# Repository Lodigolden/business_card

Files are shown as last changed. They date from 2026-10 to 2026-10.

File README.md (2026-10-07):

# Business Card

## Overview
I saw the idea for a PCB business card online, but for the most part the PCBs didn't actually do anything. I saw a fun opportunity to give anyone who's got the card a clock/thermometer that they might get some use out of.

## Use

## Build Your Own!
See the Bill of Materials (BoM) in the docs/ folder.

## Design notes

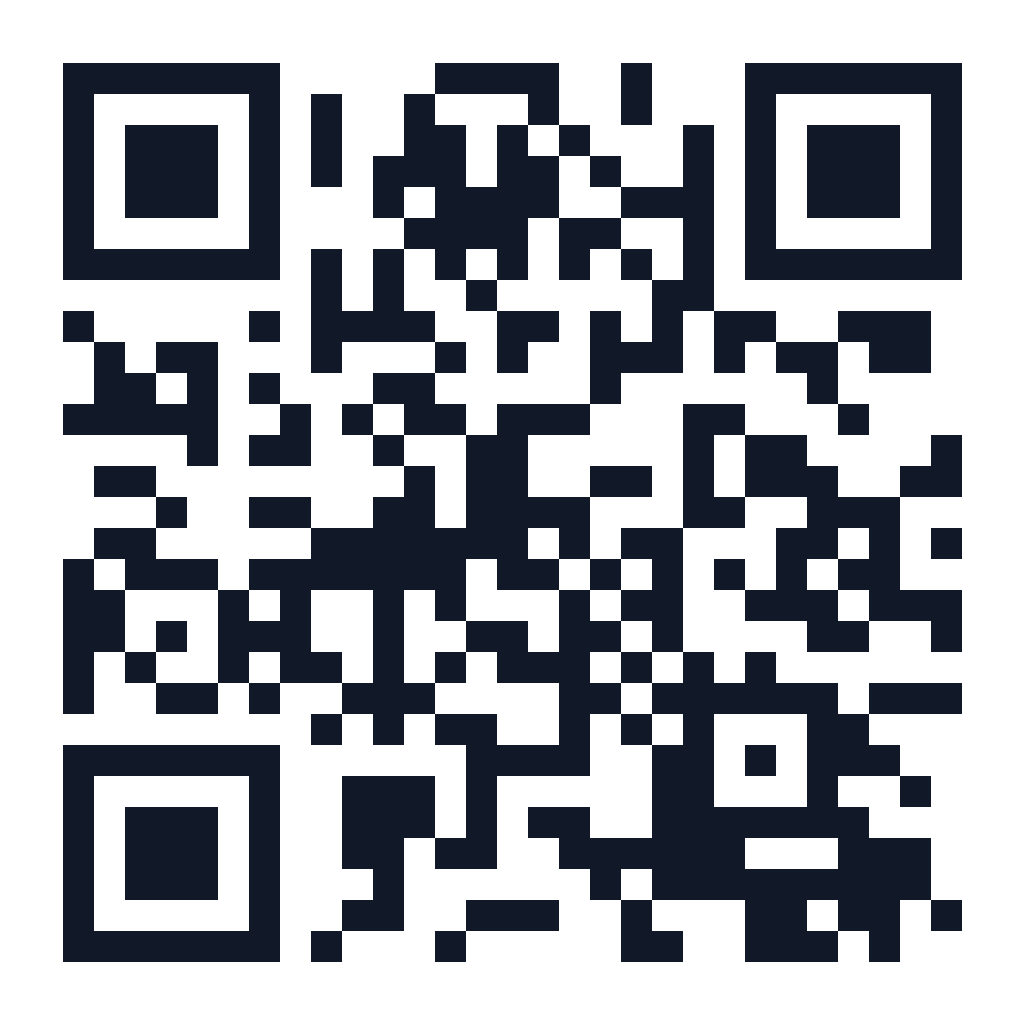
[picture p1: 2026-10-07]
docs/assets/github-qr.png

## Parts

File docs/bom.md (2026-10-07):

# Bill of Materials
| Description | MFG Part Number | QNTY |
|---|---|---|
| Battery Holder | 1057TR | 1 |
| Comparator | LMV331M5/NOPB | 1 |
| ESD Protection Diode | SP1326-01LTG | 4 |
| GPIO Expander | PCAL6416AHF,128 | 2 |
| Header | TSM-102-01-L-SV | 1 |
| Microcontroller | PIC16F15245T-I/REB | 1 |
| NMOSFET | 2N7002NXAKR | 3 |
| Pushbutton | 3983 | 2 |
| Red LED | LTST-C190KRKT | 4 |
| RTC | MCP7940MT-I/MNY | 1 |
| Supervisor | LM8365BALMF27/NOPB | 1 |
| Temp Sensor | TMP1075NDRLR | 1 |
| USB C Connector | 10164359-00011LF | 1 |
| 100nF 0402 Capacitor | CC0402KPX7R9BB104 | 15 |
| 1uF 0603 Capacitor | C0603C105K4RACTU | 6 |
| 1kOhm 0402 Resistor | ERJ-2RKF1001X | 36 |
| 10kOhm 0402 Resistor | RC0402FR-0710KL | 11 |
| 2.2uF 0603 Capacitor | GRT188R61H225KE13D | 1 |
| 20kOhm 0402 Resistor | RC0402FR-0720KL | 1 |
| 24.9Ohm 0402 Resistor | ERJ-2RKF24R9X | 4 |
| 30kOhm 0402 Resistor | RC0402FR-0730KL | 1 |
| 32.77kHz Oscillator | ECS-327MVATX-2-CN-TR3 | 1 |
| 470Ohm 0402 Resistor | RC0402FR-07470RL | 1 |
| 4.7kOhm 0402 Resistor | RK73H1ERTTP4701F | 2 |
| 470kOhm 0402 Resistor | RMCF0402FT470K | 1 |
| 5.1kOhm 0402 Resistor | ERA-2ARC512X | 2 |
| 7 Segment Display | VDMG10A0 | 4 |

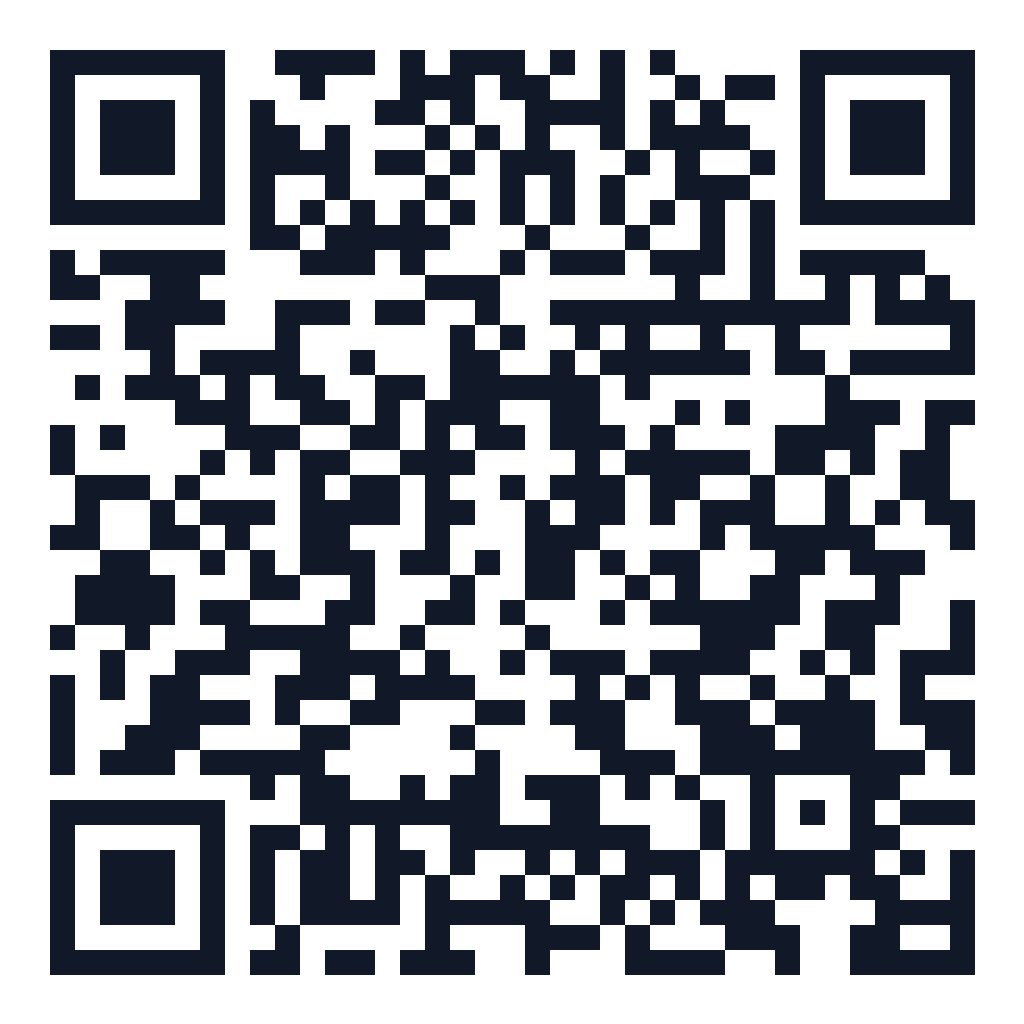
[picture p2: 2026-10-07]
docs/assets/bom-qr.png

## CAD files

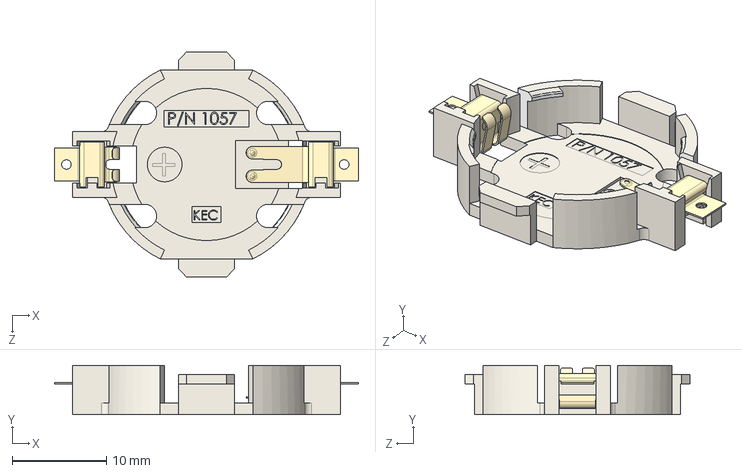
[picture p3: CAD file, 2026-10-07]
hw/components/1057TR/1057TR.step
32.3 x 5.21 x 23.9 mm

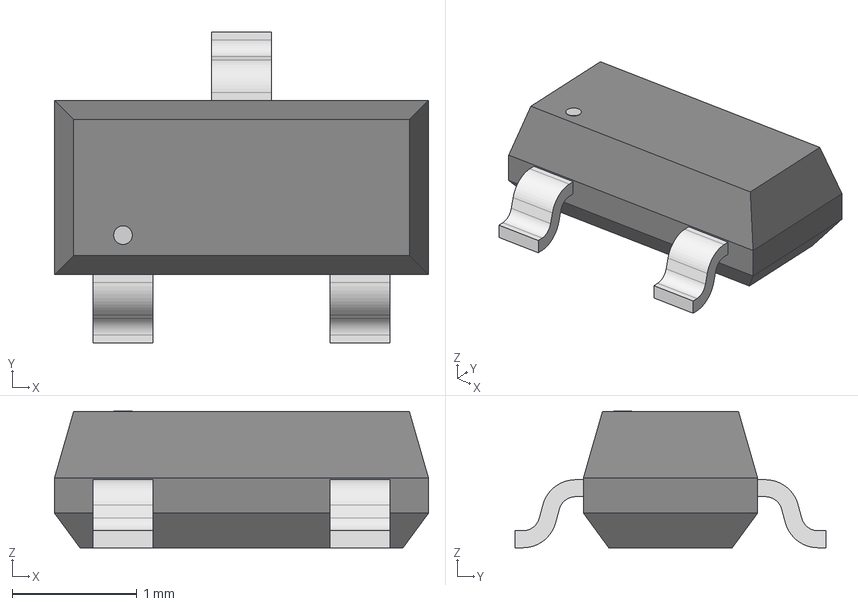
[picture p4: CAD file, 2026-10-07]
hw/components/2N7002NXAKR/TO-236AB_SOT23_NEX.step
3.00 x 2.49 x 1.09 mm

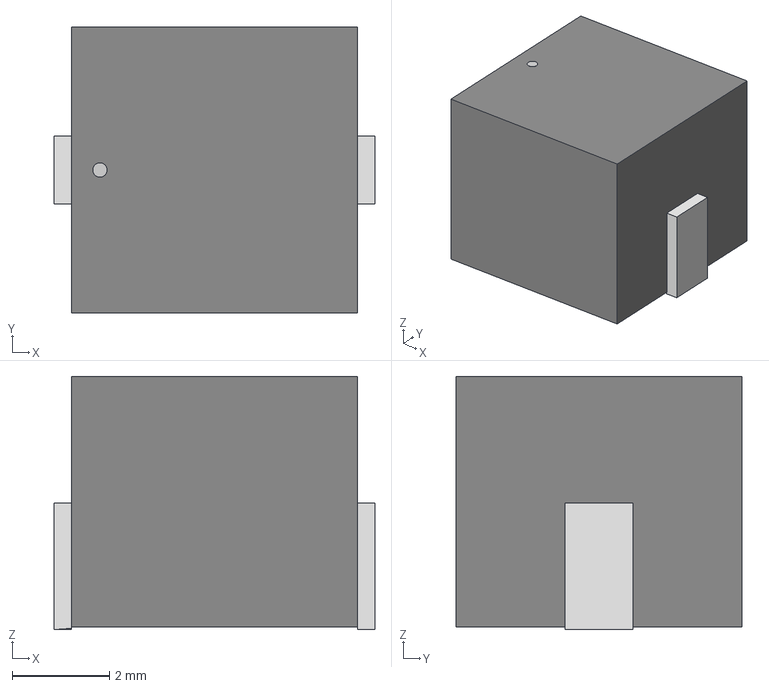
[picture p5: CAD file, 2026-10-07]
hw/components/3983/SW_3983_ADA.step
6.60 x 5.89 x 5.21 mm

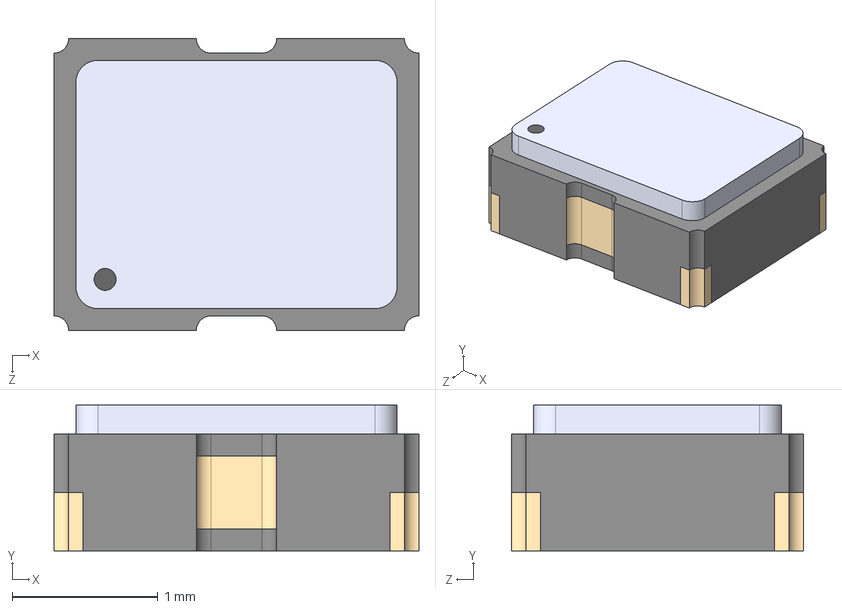
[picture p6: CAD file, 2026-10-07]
hw/components/ecs_327mvatx_2_cn_tr3/ECS-327MVATX-2-CN-TR3.step
2.50 x 1.00 x 2.00 mm

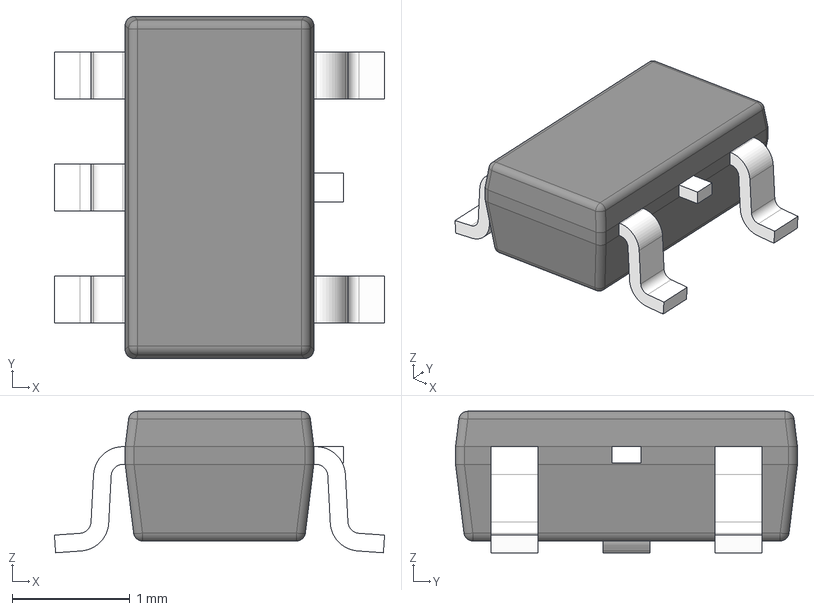
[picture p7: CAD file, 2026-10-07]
hw/components/lm8365balmf27_nopb/DBV0005A.stp
2.80 x 2.90 x 1.20 mm
BODY-SOT
LEAD-SOT x 5
LEAD-DUMMY

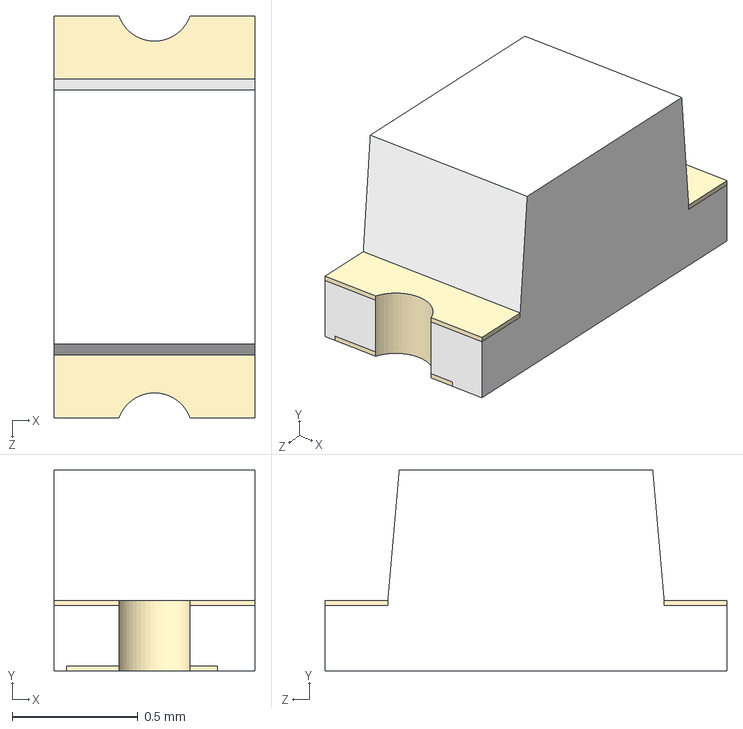
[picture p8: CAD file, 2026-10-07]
hw/components/ltst_c190krkt/LTST-C190KRKT.step
0.8 x 0.8 x 1.60 mm

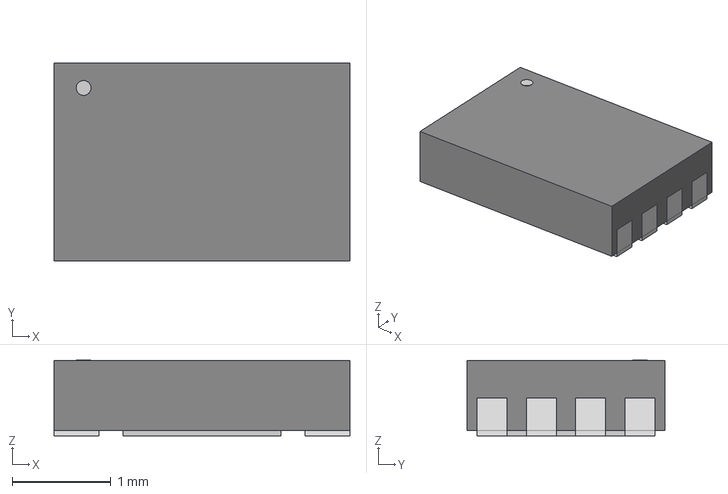
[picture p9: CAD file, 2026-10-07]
hw/components/mcp7940mt_i_mny/TDFN8_2x3MC_MCH.step
3.00 x 2.01 x 0.765 mm

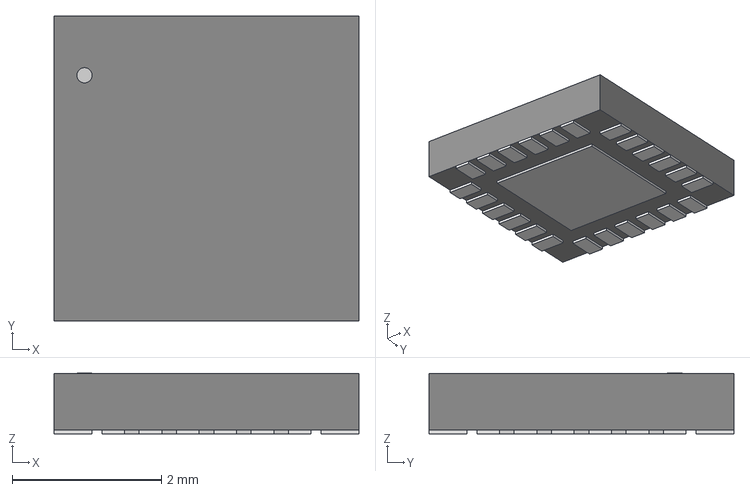
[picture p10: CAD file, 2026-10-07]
hw/components/pcal6416ahf/HWQFN24_PCAL_NXP.step
4.09 x 4.09 x 0.815 mm

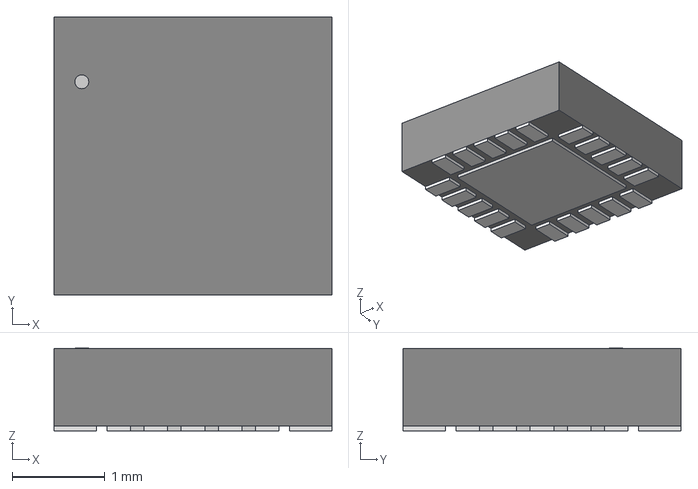
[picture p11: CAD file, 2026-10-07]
hw/components/pic16f15245t_i_reb/VQFN20_REB_MCH.step
3.00 x 3.00 x 0.892 mm

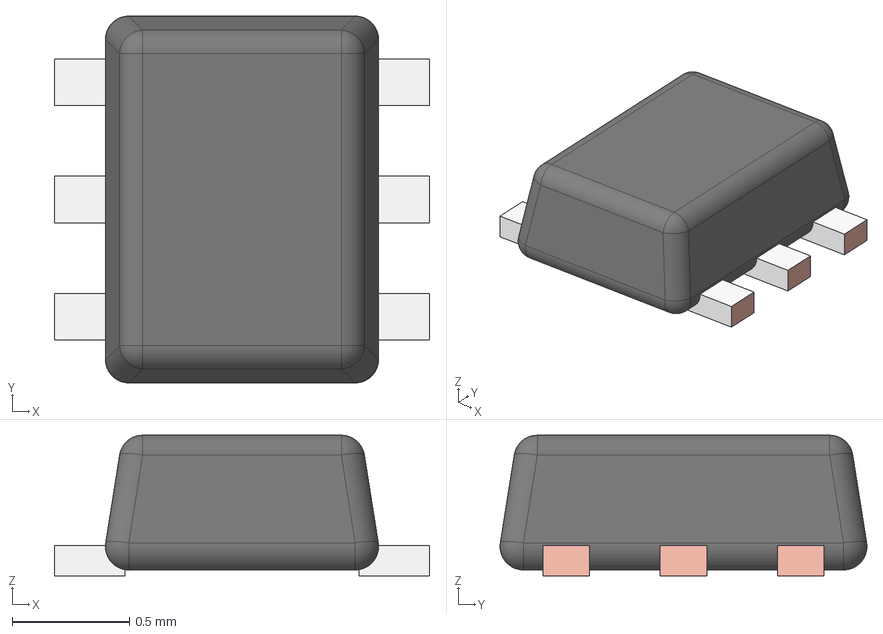
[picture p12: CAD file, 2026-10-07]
hw/components/tmp1075ndrlr/DRL0006A.stp
1.60 x 1.57 x 0.6 mm
FRAME-DRL0006A
BODY-SOT
PIN1-ID

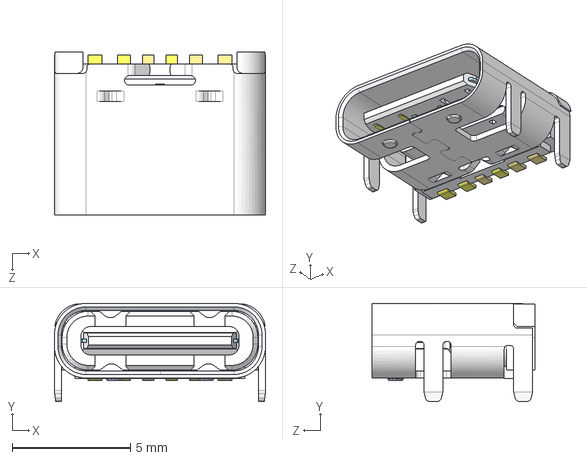
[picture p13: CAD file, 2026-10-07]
hw/components/10164359_00011LF/10164359-00011LF.step
8.94 x 4.16 x 6.90 mm

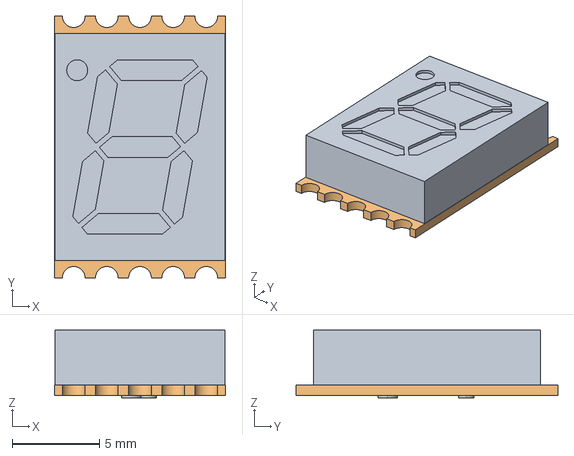
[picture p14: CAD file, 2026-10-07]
hw/components/vdmg10a0/804307_segment_display_10mm_SMD_VDMx10x0.stp
9.80 x 15.0 x 3.89 mm
4812REF_2
4812PCB_2

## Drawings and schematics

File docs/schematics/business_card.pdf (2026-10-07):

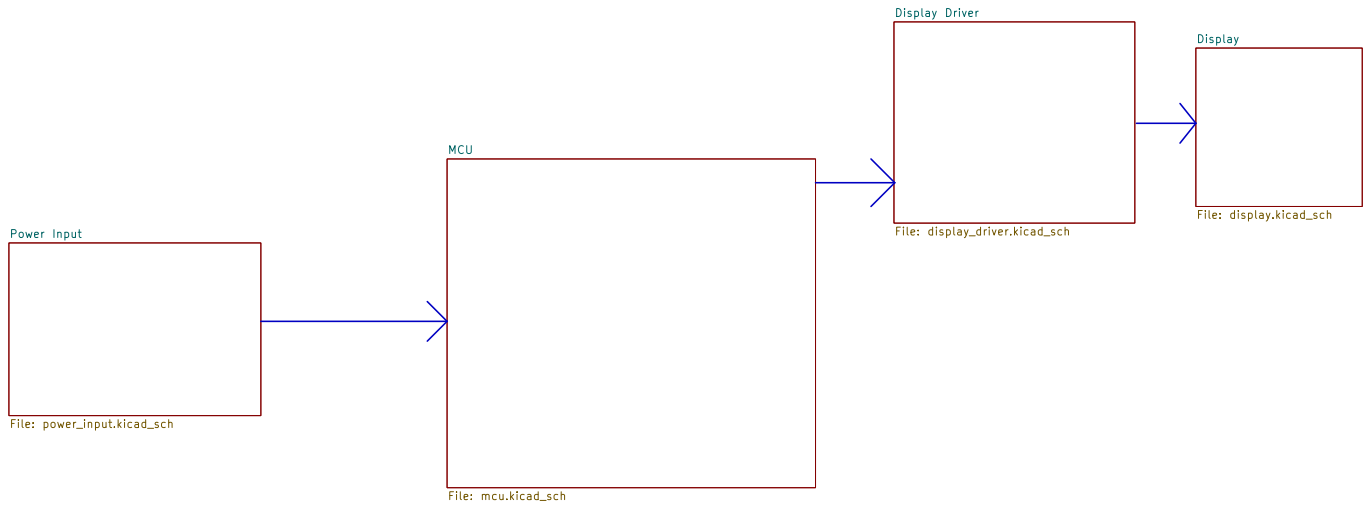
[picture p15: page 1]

File: mcu.kicad_sch Power Input File: power_input.kicad_sch

Size: A4 | Rev: A
KiCad E.D.A. 10.0.3 | Id: 1/5

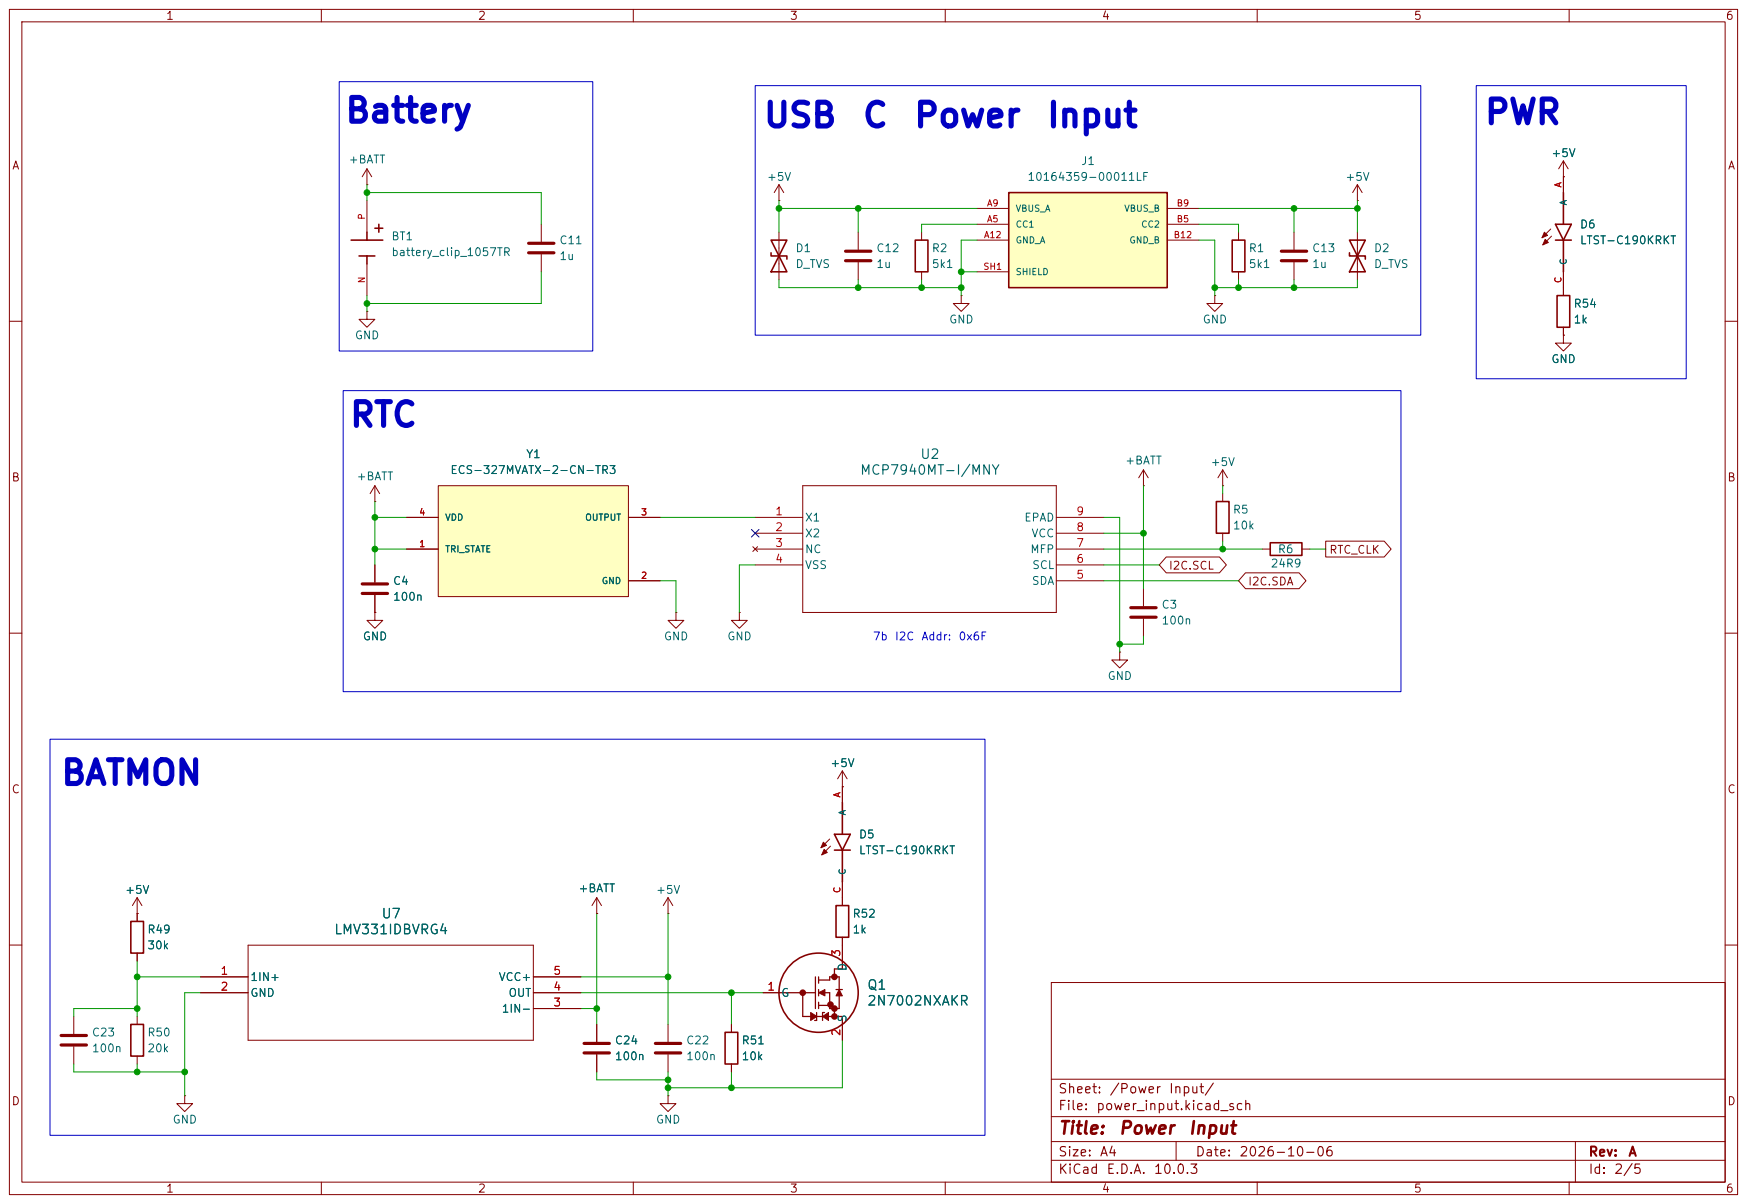
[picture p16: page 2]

7b I2C Addr: 0x6F USB C Power Input

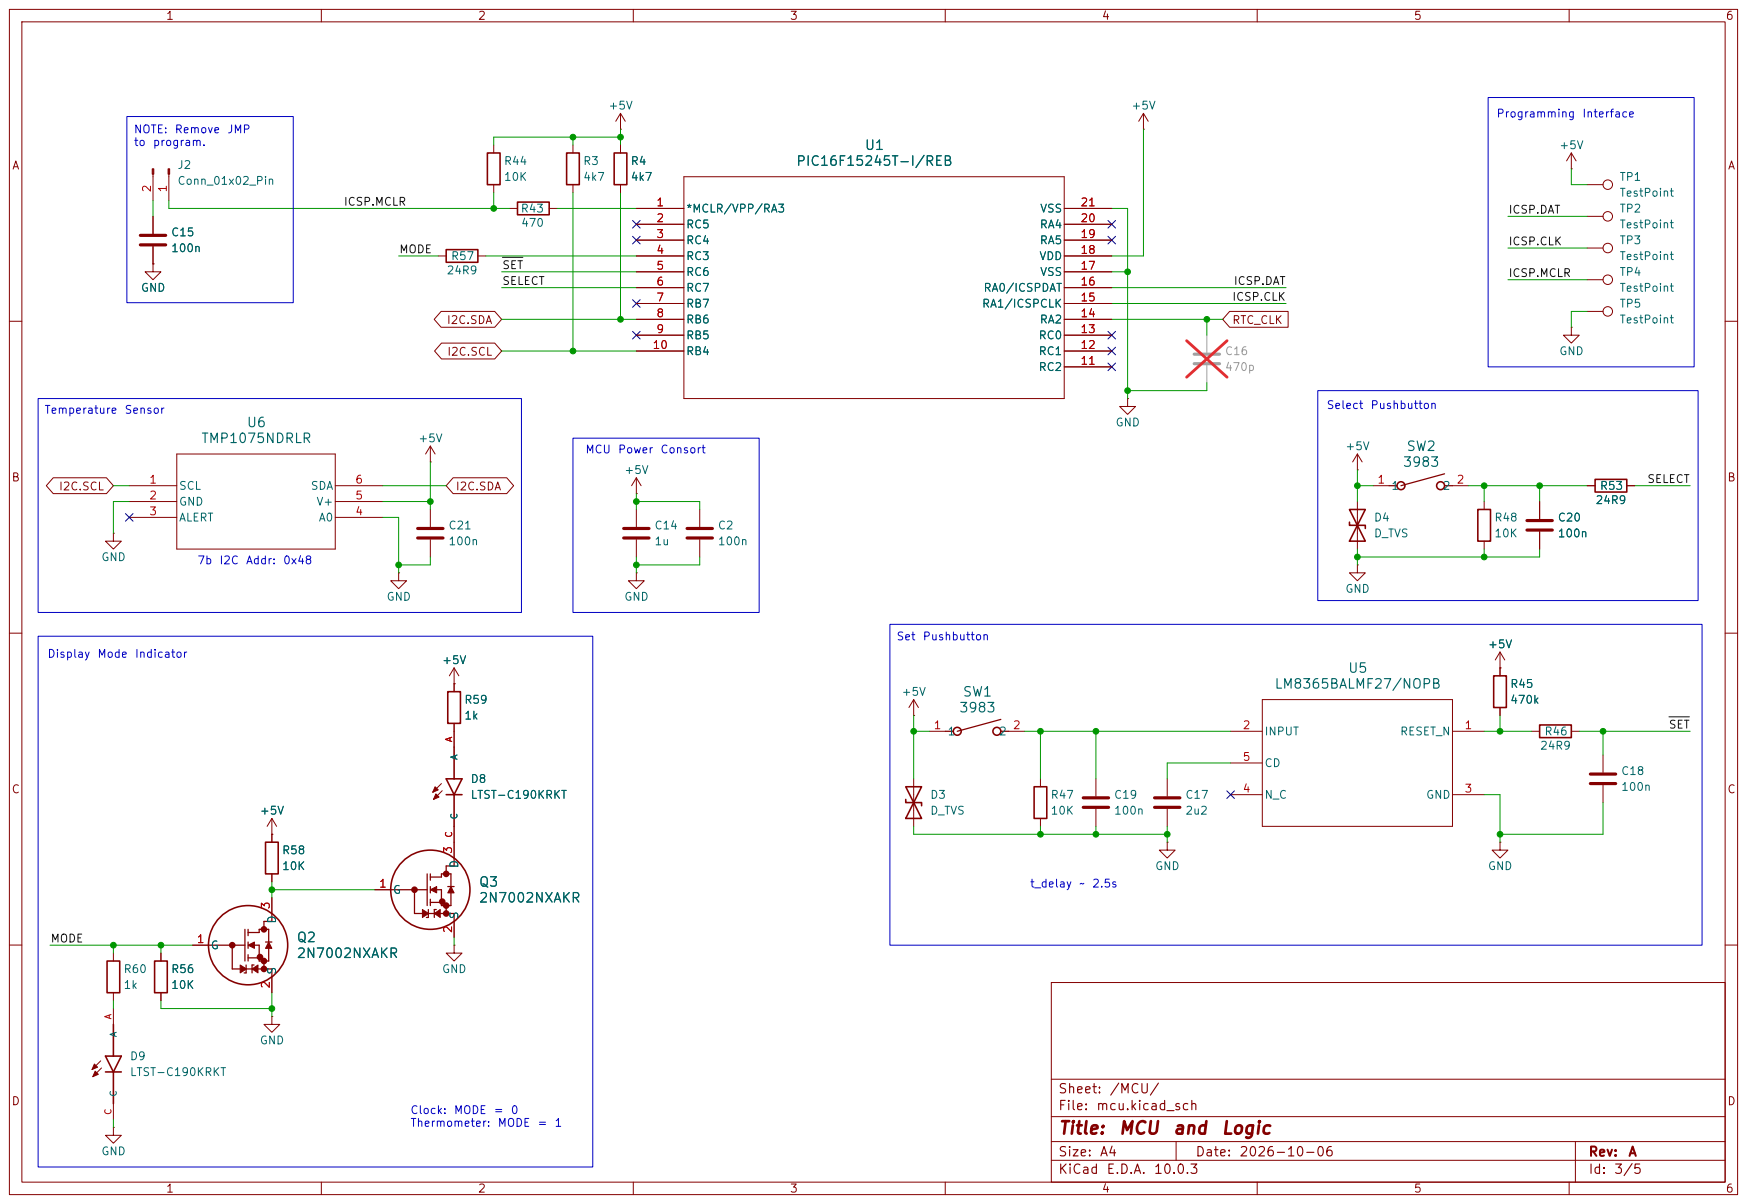
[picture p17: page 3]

Temperature Sensor NOTE: Remove JMP

File: mcu.kicad_sch
Title: MCU and Logic

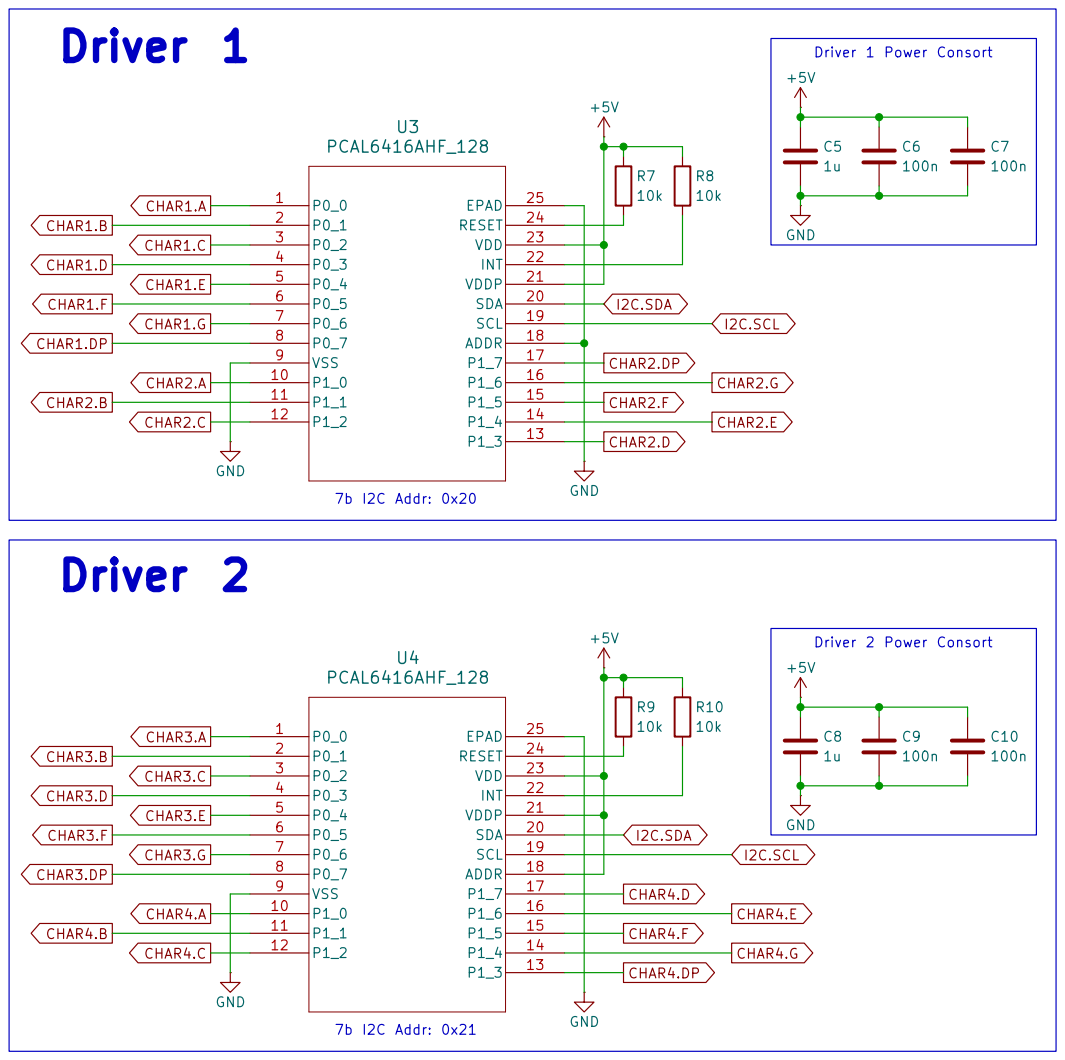
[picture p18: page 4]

Driver 1 Power Consort Driver 2

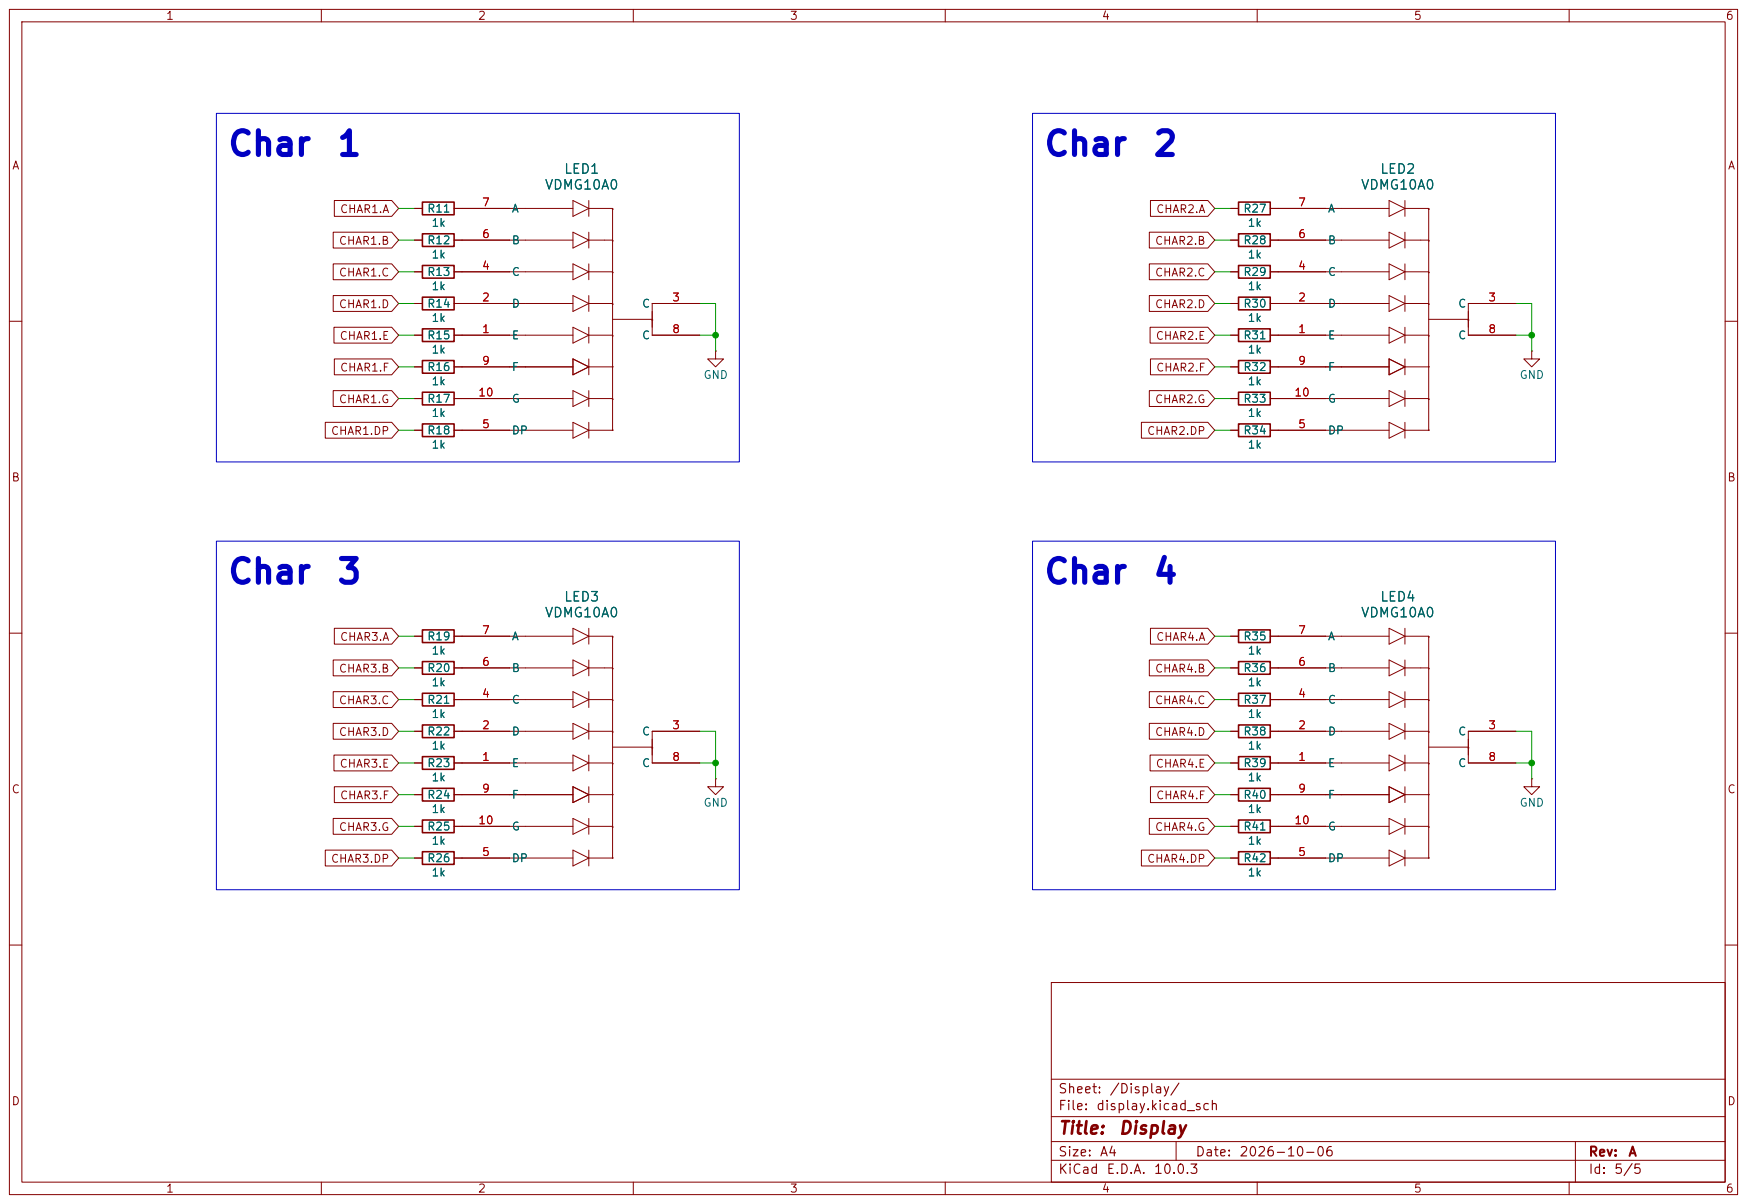
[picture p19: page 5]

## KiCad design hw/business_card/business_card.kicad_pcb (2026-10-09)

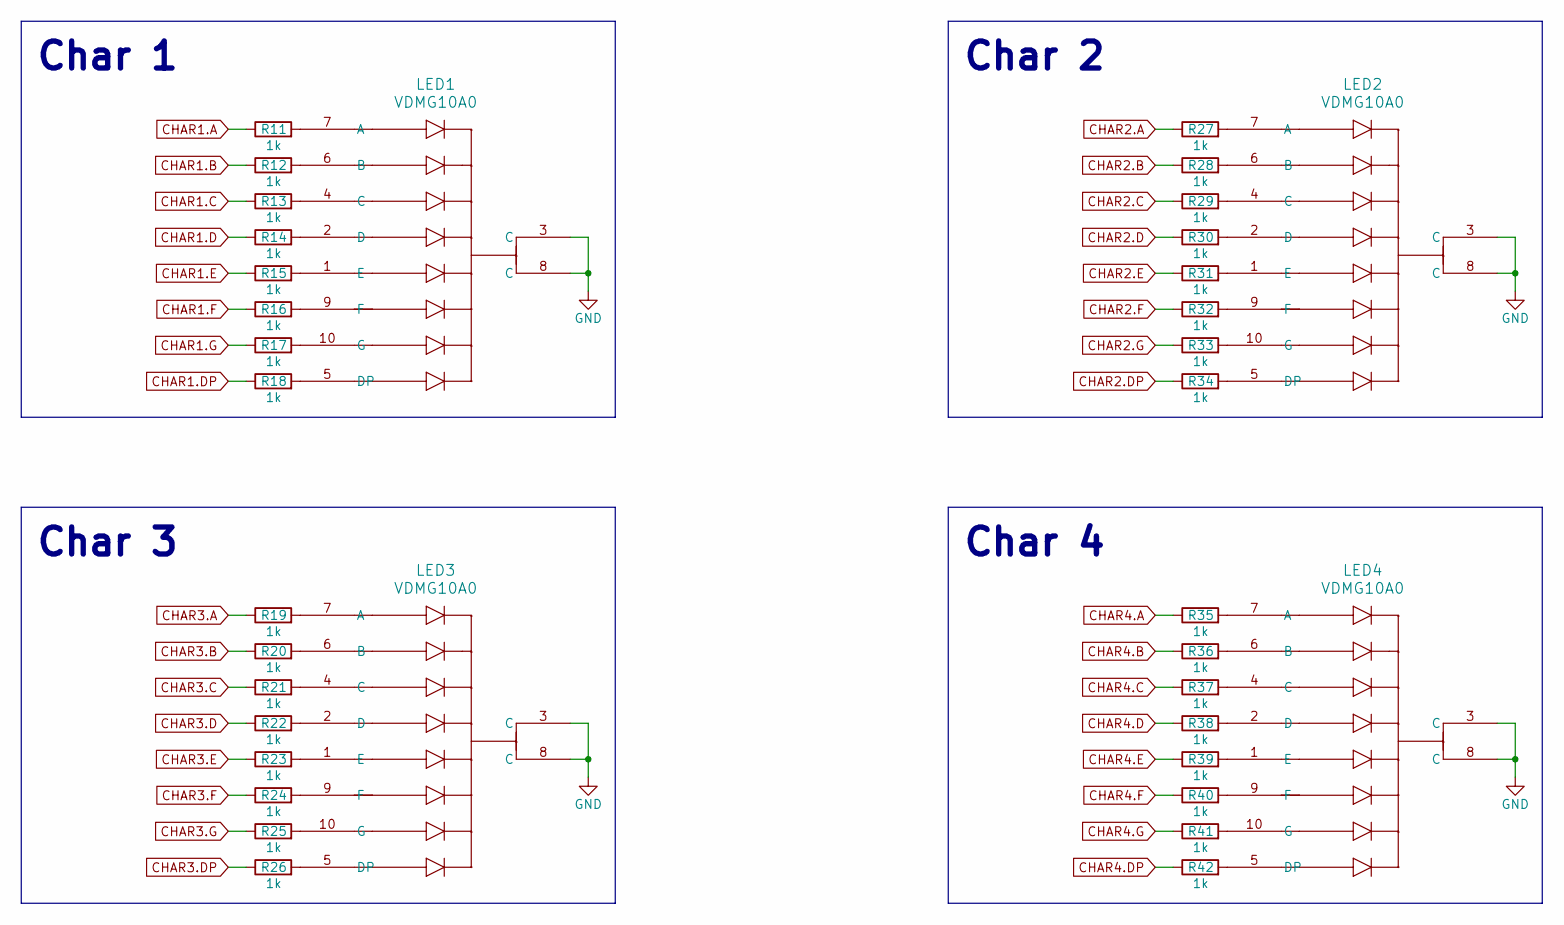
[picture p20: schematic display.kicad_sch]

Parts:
LED1, LED2, LED3, LED4: VDMG10A0; SMT_MG10A0_VIS
R11, R12, R13, R14, R15, R16, R17, R18, R19, R20, R21, R22, R23, R24, R25, R26, R27, R28, R29, R30, R31, R32, R33, R34, R35, R36, R37, R38, R39, R40, R41, R42: 1k; R_0402_1005Metric

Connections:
CHAR1.A: R11.1; also elsewhere on the board
CHAR1.B: R12.1; also elsewhere on the board
CHAR1.C: R13.1; also elsewhere on the board
CHAR1.D: R14.1; also elsewhere on the board
CHAR1.DP: R18.1; also elsewhere on the board
CHAR1.E: R15.1; also elsewhere on the board
CHAR1.F: R16.1; also elsewhere on the board
CHAR1.G: R17.1; also elsewhere on the board
CHAR2.A: R27.1; also elsewhere on the board
CHAR2.B: R28.1; also elsewhere on the board
CHAR2.C: R29.1; also elsewhere on the board
CHAR2.D: R30.1; also elsewhere on the board
CHAR2.DP: R34.1; also elsewhere on the board
CHAR2.E: R31.1; also elsewhere on the board
CHAR2.F: R32.1; also elsewhere on the board
CHAR2.G: R33.1; also elsewhere on the board
CHAR3.A: R19.1; also elsewhere on the board
CHAR3.B: R20.1; also elsewhere on the board
CHAR3.C: R21.1; also elsewhere on the board
CHAR3.D: R22.1; also elsewhere on the board
CHAR3.DP: R26.1; also elsewhere on the board
CHAR3.E: R23.1; also elsewhere on the board
CHAR3.F: R24.1; also elsewhere on the board
CHAR3.G: R25.1; also elsewhere on the board
CHAR4.A: R35.1; also elsewhere on the board
CHAR4.B: R36.1; also elsewhere on the board
CHAR4.C: R37.1; also elsewhere on the board
CHAR4.D: R38.1; also elsewhere on the board
CHAR4.DP: R42.1; also elsewhere on the board
CHAR4.E: R39.1; also elsewhere on the board
CHAR4.F: R40.1; also elsewhere on the board
CHAR4.G: R41.1; also elsewhere on the board
GND: LED1.3 (C), LED1.8 (C), LED2.3 (C), LED2.8 (C), LED3.3 (C), LED3.8 (C), LED4.3 (C), LED4.8 (C); also elsewhere on the board
unnamed: LED1.7 (A), R11.2
unnamed: LED1.6 (B), R12.2
unnamed: LED1.4 (C), R13.2
unnamed: LED1.2 (D), R14.2
unnamed: LED1.5 (DP), R18.2
unnamed: LED1.1 (E), R15.2
unnamed: LED1.9 (F), R16.2
unnamed: LED1.10 (G), R17.2
unnamed: LED2.7 (A), R27.2
unnamed: LED2.6 (B), R28.2
unnamed: LED2.4 (C), R29.2
unnamed: LED2.2 (D), R30.2
unnamed: LED2.5 (DP), R34.2
unnamed: LED2.1 (E), R31.2
unnamed: LED2.9 (F), R32.2
unnamed: LED2.10 (G), R33.2
unnamed: LED3.7 (A), R19.2
unnamed: LED3.6 (B), R20.2
unnamed: LED3.4 (C), R21.2
unnamed: LED3.2 (D), R22.2
unnamed: LED3.5 (DP), R26.2
unnamed: LED3.1 (E), R23.2
unnamed: LED3.9 (F), R24.2
unnamed: LED3.10 (G), R25.2
unnamed: LED4.7 (A), R35.2
unnamed: LED4.6 (B), R36.2
unnamed: LED4.4 (C), R37.2
unnamed: LED4.2 (D), R38.2
unnamed: LED4.5 (DP), R42.2
unnamed: LED4.1 (E), R39.2
unnamed: LED4.9 (F), R40.2
unnamed: LED4.10 (G), R41.2

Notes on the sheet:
Char 3
Char 4
Char 2
Char 1

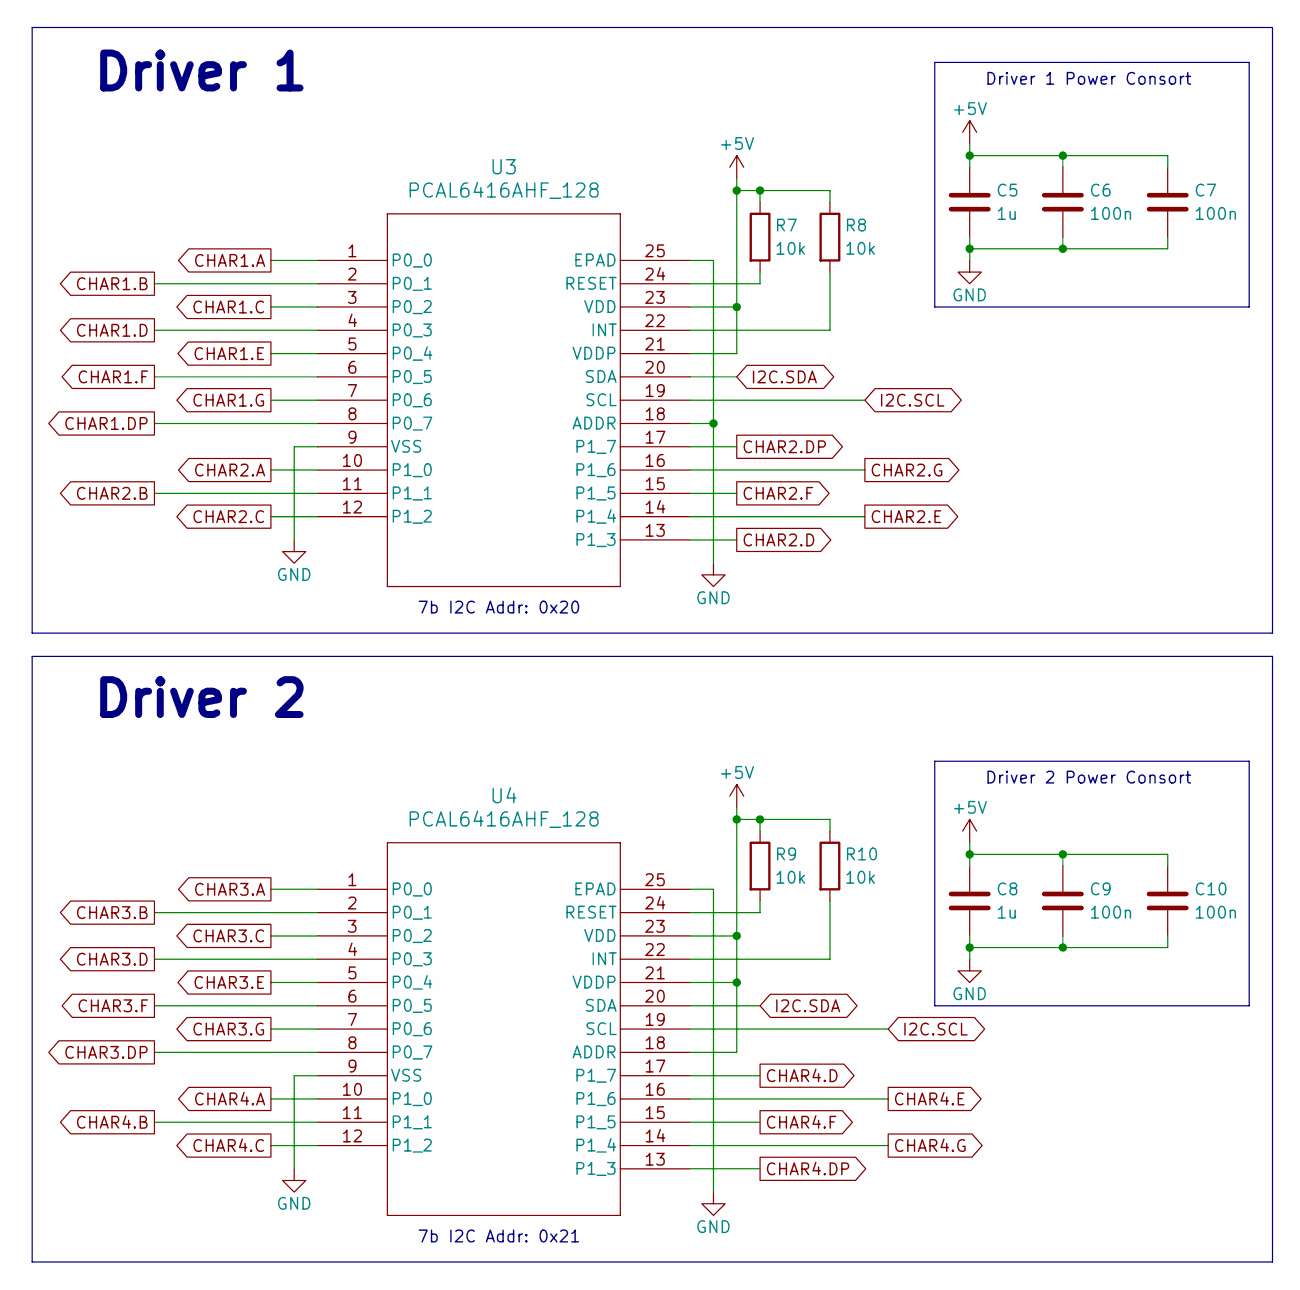
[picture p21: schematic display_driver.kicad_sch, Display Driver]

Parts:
C5, C8: 1u; C_0603_1608Metric
C6, C7, C9, C10: 100n; C_0402_1005Metric
R7, R8, R9, R10: 10k; R_0402_1005Metric
U3, U4: PCAL6416AHF_128; HWQFN24_PCAL_NXP

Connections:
+5V: C5.1, C6.1, C7.1, C8.1, C9.1, C10.1, R7.1, R8.1, R9.1, R10.1, U3.21 (VDDP), U3.23 (VDD), U4.18 (ADDR), U4.21 (VDDP), U4.23 (VDD); also elsewhere on the board
CHAR1.A: U3.1 (P0_0); also elsewhere on the board
CHAR1.B: U3.2 (P0_1); also elsewhere on the board
CHAR1.C: U3.3 (P0_2); also elsewhere on the board
CHAR1.D: U3.4 (P0_3); also elsewhere on the board
CHAR1.DP: U3.8 (P0_7); also elsewhere on the board
CHAR1.E: U3.5 (P0_4); also elsewhere on the board
CHAR1.F: U3.6 (P0_5); also elsewhere on the board
CHAR1.G: U3.7 (P0_6); also elsewhere on the board
CHAR2.A: U3.10 (P1_0); also elsewhere on the board
CHAR2.B: U3.11 (P1_1); also elsewhere on the board
CHAR2.C: U3.12 (P1_2); also elsewhere on the board
CHAR2.D: U3.13 (P1_3); also elsewhere on the board
CHAR2.DP: U3.17 (P1_7); also elsewhere on the board
CHAR2.E: U3.14 (P1_4); also elsewhere on the board
CHAR2.F: U3.15 (P1_5); also elsewhere on the board
CHAR2.G: U3.16 (P1_6); also elsewhere on the board
CHAR3.A: U4.1 (P0_0); also elsewhere on the board
CHAR3.B: U4.2 (P0_1); also elsewhere on the board
CHAR3.C: U4.3 (P0_2); also elsewhere on the board
CHAR3.D: U4.4 (P0_3); also elsewhere on the board
CHAR3.DP: U4.8 (P0_7); also elsewhere on the board
CHAR3.E: U4.5 (P0_4); also elsewhere on the board
CHAR3.F: U4.6 (P0_5); also elsewhere on the board
CHAR3.G: U4.7 (P0_6); also elsewhere on the board
CHAR4.A: U4.10 (P1_0); also elsewhere on the board
CHAR4.B: U4.11 (P1_1); also elsewhere on the board
CHAR4.C: U4.12 (P1_2); also elsewhere on the board
CHAR4.D: U4.17 (P1_7); also elsewhere on the board
CHAR4.DP: U4.13 (P1_3); also elsewhere on the board
CHAR4.E: U4.16 (P1_6); also elsewhere on the board
CHAR4.F: U4.15 (P1_5); also elsewhere on the board
CHAR4.G: U4.14 (P1_4); also elsewhere on the board
GND: C5.2, C6.2, C7.2, C8.2, C9.2, C10.2, U3.9 (VSS), U3.18 (ADDR), U3.25 (EPAD), U4.9 (VSS), U4.25 (EPAD); also elsewhere on the board
I2C.SCL: U3.19 (SCL), U4.19 (SCL); also elsewhere on the board
I2C.SDA: U3.20 (SDA), U4.20 (SDA); also elsewhere on the board
unnamed: R8.2, U3.22 (INT)
unnamed: R7.2, U3.24 (RESET)
unnamed: R10.2, U4.22 (INT)
unnamed: R9.2, U4.24 (RESET)

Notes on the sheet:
Driver 2 Power Consort
Driver 2
Driver 1 Power Consort
7b I2C Addr: 0x21
Driver 1
7b I2C Addr: 0x20

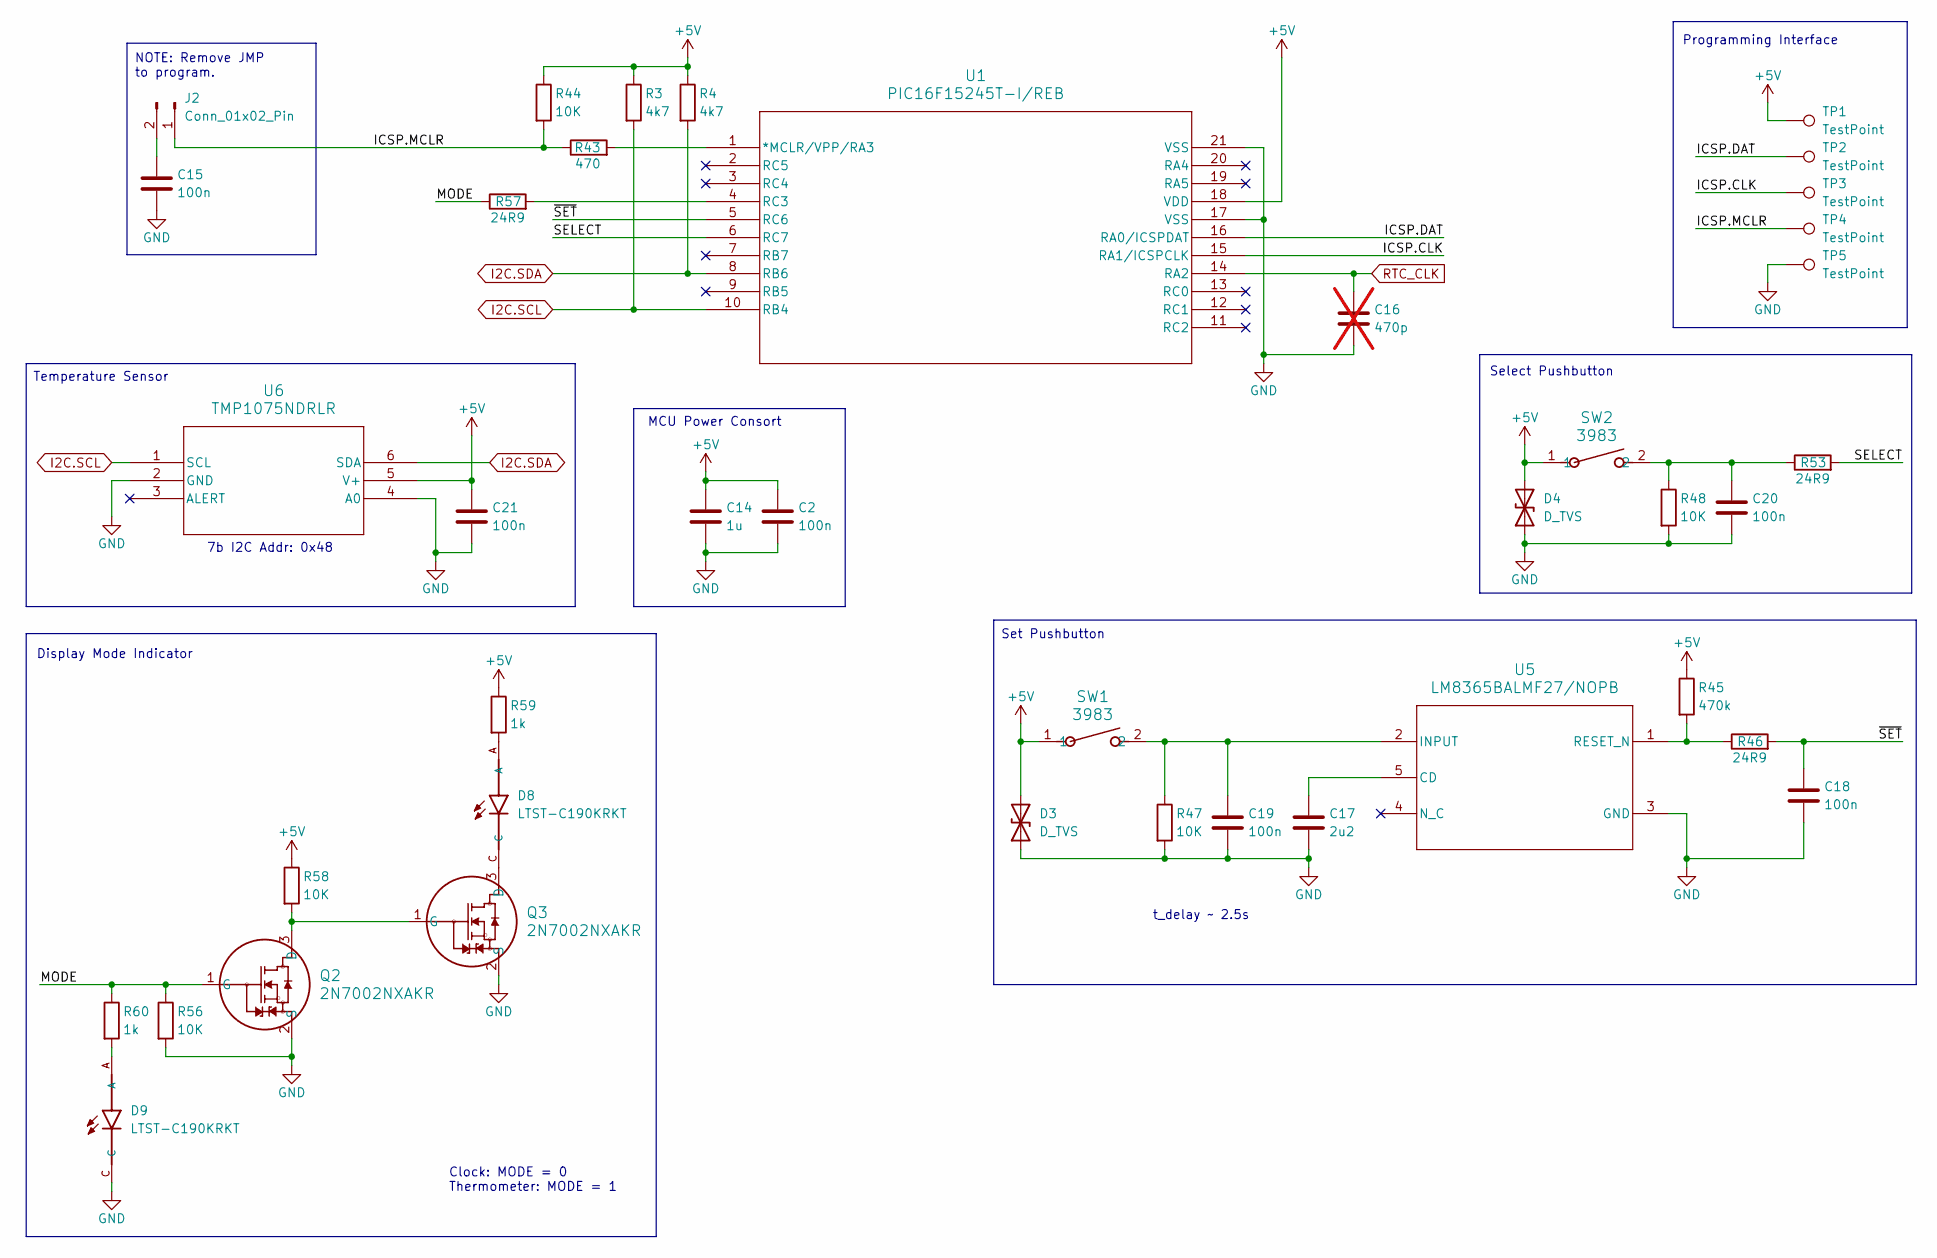
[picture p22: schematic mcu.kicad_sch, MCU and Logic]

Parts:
C2, C15, C18, C19, C20, C21: 100n; C_0402_1005Metric
C14: 1u; C_0603_1608Metric
C16: 470p; C_0402_1005Metric; not fitted
C17: 2u2; C_0603_1608Metric
D3, D4: D_TVS; D_SOD-523
D8, D9: LTST-C190KRKT; LEDC1608X35N
J2: Conn_01x02_Pin; PinHeader_1x02_P2.54mm_Vertical_SMD_Pin1Right
Q2, Q3: 2N7002NXAKR; TO-236AB_SOT23_NEX
R3, R4: 4k7; R_0402_1005Metric
R43: 470; R_0402_1005Metric
R44, R47, R48, R56, R58: 10K; R_0402_1005Metric
R45: 470k; R_0402_1005Metric
R46, R53, R57: 24R9; R_0402_1005Metric
R59, R60: 1k; R_0402_1005Metric
SW1, SW2: 3983; SW_3983_ADA
TP1, TP2, TP3, TP4, TP5: TestPoint; TestPoint_Pad_D2.5mm
U1: PIC16F15245T-I/REB; VQFN20_REB_MCH
U5: LM8365BALMF27/NOPB; DBV0005A_L
U6: TMP1075NDRLR; SOT5X3-6_DRL_TEX

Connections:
+5V: C2.1, C14.1, C21.1, D3.2 (A2), D4.2 (A2), R3.1, R4.1, R44.1, R45.1, R58.1, R59.1, SW1.1, SW2.1, TP1.1 (1_1), U1.18 (VDD), U6.5 (V+); also elsewhere on the board
/MCU/ICSP.CLK: TP3.1 (1_1), U1.15 (RA1/ICSPCLK)
/MCU/ICSP.DAT: TP2.1 (1_1), U1.16 (RA0/ICSPDAT)
/MCU/ICSP.MCLR: J2.1, R43.1, R44.2, TP4.1 (1_1)
/MCU/MODE: Q2.1 (G), R56.1, R57.1, R60.1
/MCU/SELECT: R53.2, U1.6 (RC7)
/MCU/~SET: C18.1, R46.2, U1.5 (RC6)
GND: C2.2, C14.2, C15.2, C16.2, C17.2, C18.2, C19.2, C20.2, C21.2, D3.1 (A1), D4.1 (A1), D9.C, Q2.2 (S), Q3.2 (S), R47.2, R48.2, R56.2, TP5.1 (1_1), U1.17 (VSS), U1.21 (VSS), U5.3 (GND), U6.2 (GND), U6.4 (A0); also elsewhere on the board
I2C.SCL: R3.2, U1.10 (RB4), U6.1 (SCL); also elsewhere on the board
I2C.SDA: R4.2, U1.8 (RB6), U6.6 (SDA); also elsewhere on the board
unnamed: C20.1, R48.1, R53.1, SW2.2
unnamed: D8.A, R59.2
unnamed: D9.A, R60.2
unnamed: C15.1, J2.2
unnamed: Q2.3 (D), Q3.1 (G), R58.2
unnamed: D8.C, Q3.3 (D)
unnamed: R43.2, U1.1 (*MCLR/VPP/RA3)
unnamed: R57.2, U1.4 (RC3)
unnamed: C17.1, U5.5 (CD)
unnamed: C19.1, R47.1, SW1.2, U5.2 (INPUT)
unnamed: R45.2, R46.1, U5.1 (RESET_N)
RTC_CLK: C16.1, U1.14 (RA2); also elsewhere on the board

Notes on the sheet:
Temperature Sensor
Display Mode Indicator
NOTE: Remove JMP to program.
7b I2C Addr: 0x48
MCU Power Consort
Programming Interface
Select Pushbutton
Set Pushbutton
t_delay ~ 2.5s
Clock: MODE = 0 Thermometer: MODE = 1

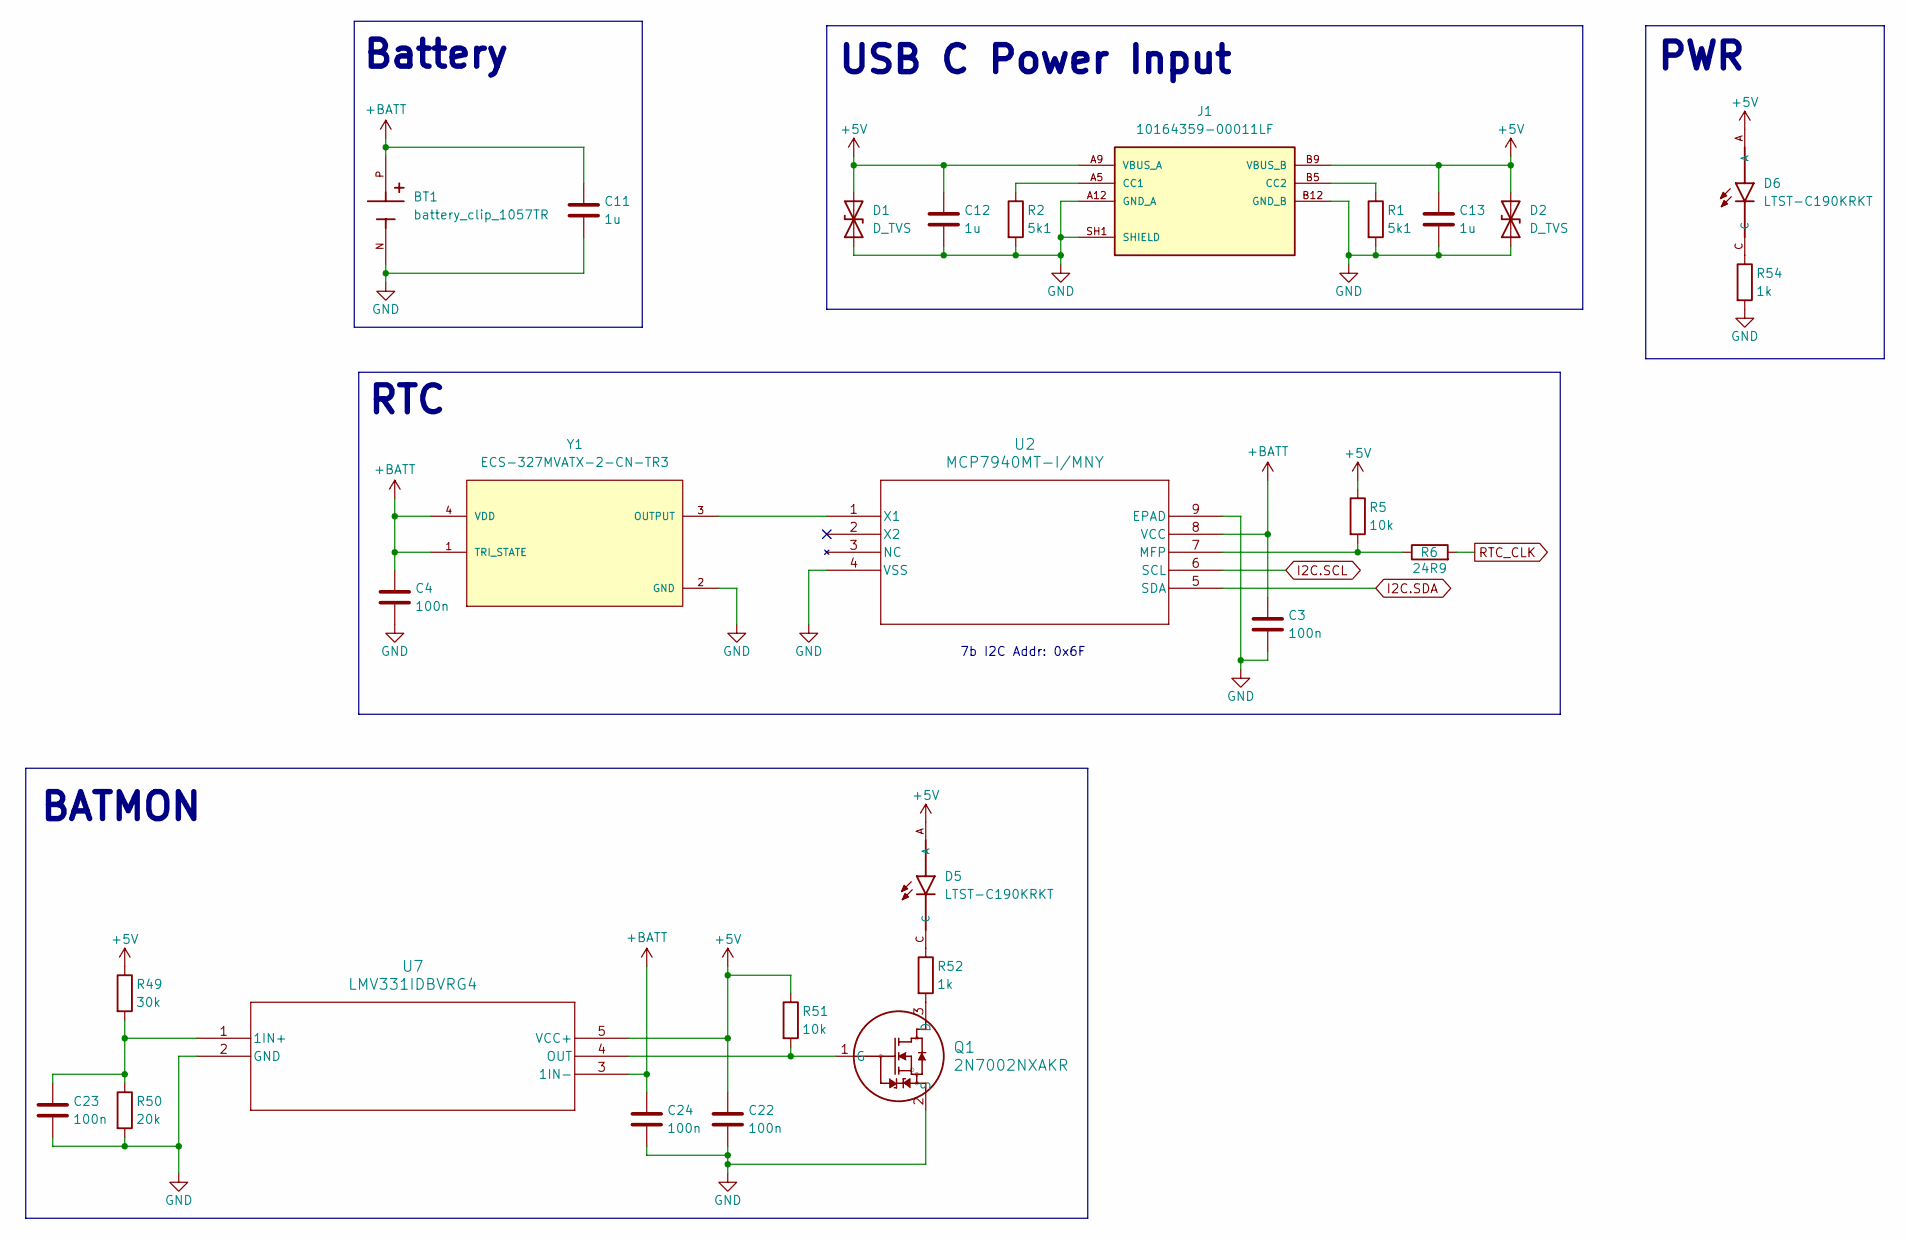
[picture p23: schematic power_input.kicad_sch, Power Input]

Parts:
BT1: battery_clip_1057TR; BAT_1057TR; PARTREV H
C3, C4, C22, C23, C24: 100n; C_0402_1005Metric
C11, C12, C13: 1u; C_0603_1608Metric
D1, D2: D_TVS; D_SOD-523
D5, D6: LTST-C190KRKT; LEDC1608X35N
J1: 10164359-00011LF; AMPHENOL_10164359-00011LF; PARTREV A
Q1: 2N7002NXAKR; TO-236AB_SOT23_NEX
R1, R2: 5k1; R_0402_1005Metric
R5, R51: 10k; R_0402_1005Metric
R6: 24R9; R_0402_1005Metric
R49: 30k; R_0402_1005Metric
R50: 20k; R_0402_1005Metric
R52, R54: 1k; R_0402_1005Metric
U2: MCP7940MT-I/MNY; TDFN8_2x3MC_MCH
U7: LMV331IDBVRG4; DBV5
Y1: ECS-327MVATX-2-CN-TR3; OSC_ECS-2520S25-250-FN-TR; PARTREV 2017

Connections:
+5V: C12.1, C13.1, C22.1, D1.2 (A2), D2.2 (A2), D5.A, D6.A, J1.A9 (VBUS_A), J1.B9 (VBUS_B), R5.1, R49.1, R51.1, U7.5 (VCC+); also elsewhere on the board
+BATT: BT1.P, C3.1, C4.1, C11.1, C24.1, U2.8 (VCC), U7.3 (1IN-), Y1.1 (TRI_STATE), Y1.4 (VDD)
GND: BT1.N, C3.2, C4.2, C11.2, C12.2, C13.2, C22.2, C23.2, C24.2, D1.1 (A1), D2.1 (A1), J1.A12 (GND_A), J1.B12 (GND_B), J1.SH1 (SHIELD), J1.SH2 (SHIELD), J1.SH3 (SHIELD), J1.SH4 (SHIELD), Q1.2 (S), R1.2, R2.2, R50.2, R54.2, U2.4 (VSS), U2.9 (EPAD), U7.2 (GND), Y1.2 (GND); also elsewhere on the board
I2C.SCL: U2.6 (SCL); also elsewhere on the board
I2C.SDA: U2.5 (SDA); also elsewhere on the board
unnamed: D5.C, R52.1
unnamed: D6.C, R54.1
unnamed: J1.A5 (CC1), R2.1
unnamed: J1.B5 (CC2), R1.1
unnamed: Q1.3 (D), R52.2
unnamed: Q1.1 (G), R51.2, U7.4 (OUT)
unnamed: R5.2, R6.1, U2.7 (MFP)
unnamed: U2.1 (X1), Y1.3 (OUTPUT)
unnamed: C23.1, R49.2, R50.1, U7.1 (1IN+)
RTC_CLK: R6.2; also elsewhere on the board

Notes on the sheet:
RTC
USB C Power Input
7b I2C Addr: 0x6F
Battery
PWR
BATMON

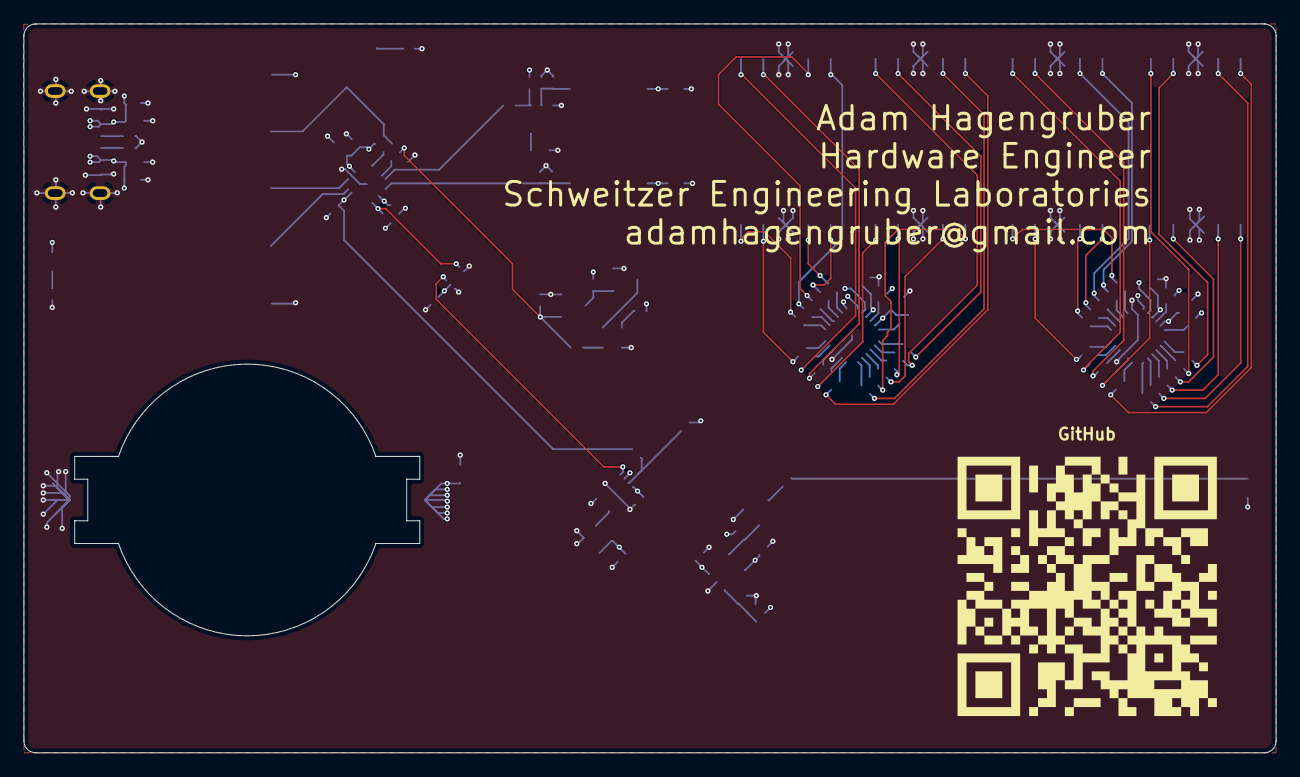
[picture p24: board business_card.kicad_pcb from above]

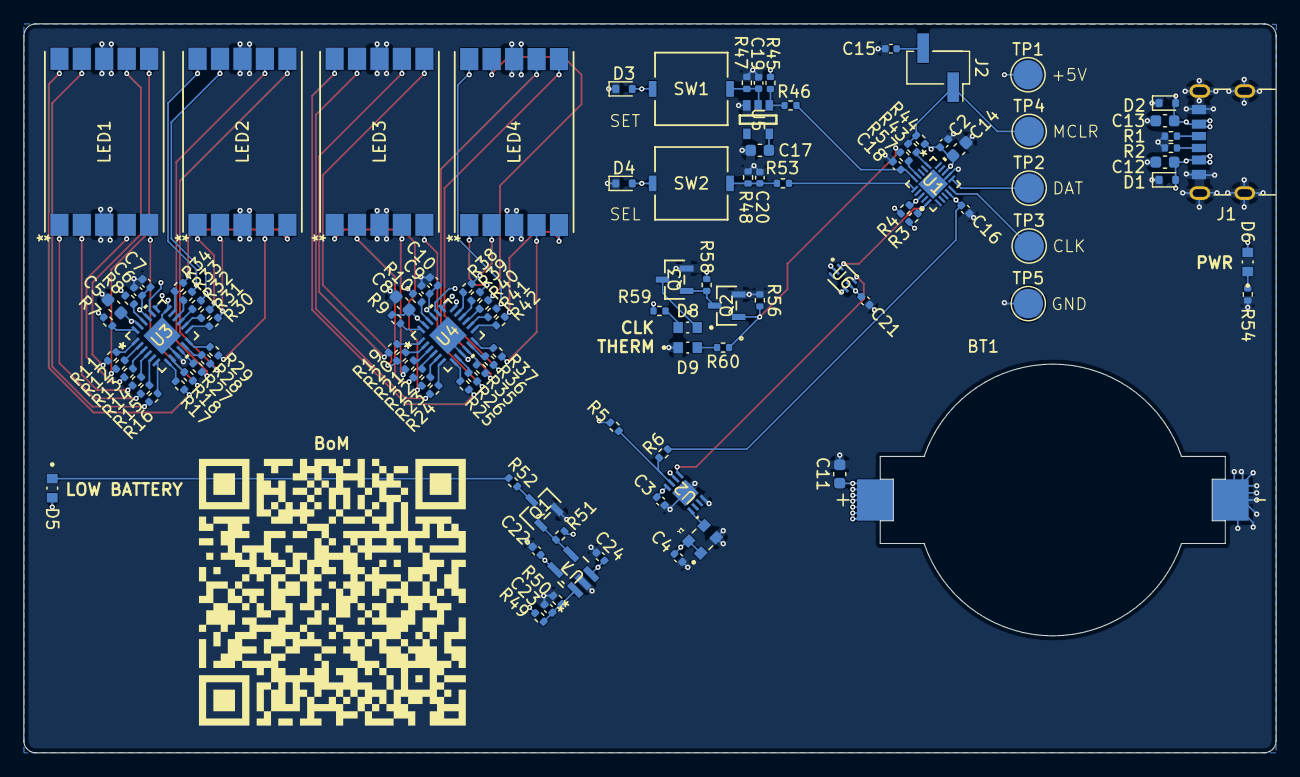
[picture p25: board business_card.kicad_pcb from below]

Board: 4 copper layers, 106.0 x 61.7 mm, 115 parts (115 on the bottom side), 100 nets.

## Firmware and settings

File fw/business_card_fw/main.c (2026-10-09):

////////////////////////////////////////////////////////////////////////////////////////////////////
// Definitions
////////////////////////////////////////////////////////////////////////////////////////////////////
#define _XTAL_FREQ 32000000 // 32 MHz Internal Oscillator

////////////////////////////////////////////////////////////////////////////////////////////////////
// Device Configuration
////////////////////////////////////////////////////////////////////////////////////////////////////
#include <xc.h>

#pragma config CONFIG1 = 0x1101

////////////////////////////////////////////////////////////////////////////////////////////////////
// Include(s)
////////////////////////////////////////////////////////////////////////////////////////////////////
#include "drivers/display_mode_indicator.h"
#include "src/config.h"

int main()
{
   config();

   while(1)
   {
      // System State Machine

      // set_display_indicator_mode();
      set_display_indicator_mode(CLOCK);
      __delay_ms(500);
      set_display_indicator_mode(THERM);
      __delay_ms(500);
   }

   return 0;
}

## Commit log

2026-10-07 BoM complete
    [business_card-B_Cu.gbr, business_card-B_Mask.gbr, business_card-B_Paste.gbr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]
2026-10-07 HW work complete
    [business_card-B_Cu.gbr, business_card-B_Mask.gbr, business_card-B_Paste.gbr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]
2026-10-08 Updated via diameters
    [business_card-B_Cu.gbr, business_card-B_Mask.gbr, business_card-B_Paste.gbr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]
2026-10-09 Added configuration code and driver for mode select LED
2026-11-07 Updates to i2c library
2026-11-10 Refresh commit before starting to modify I2C library
